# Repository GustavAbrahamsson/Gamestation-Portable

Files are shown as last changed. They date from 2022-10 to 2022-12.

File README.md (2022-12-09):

# Gamestation-Portable

A portable gaming console with a 128x64 OLED monochrome screen, two D-pads and an ESP32-S2

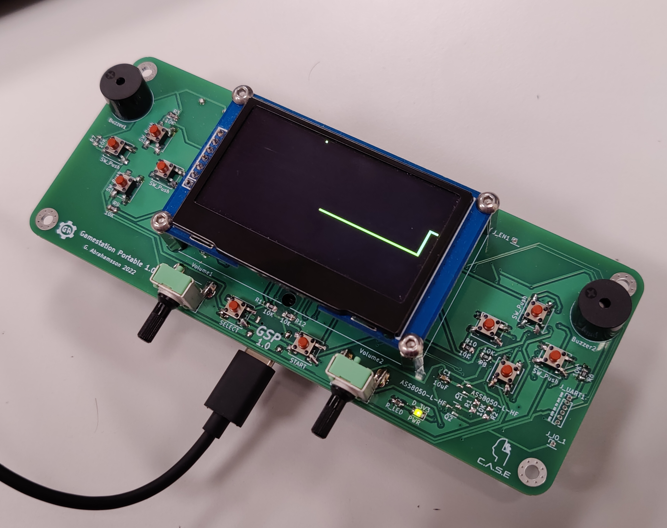
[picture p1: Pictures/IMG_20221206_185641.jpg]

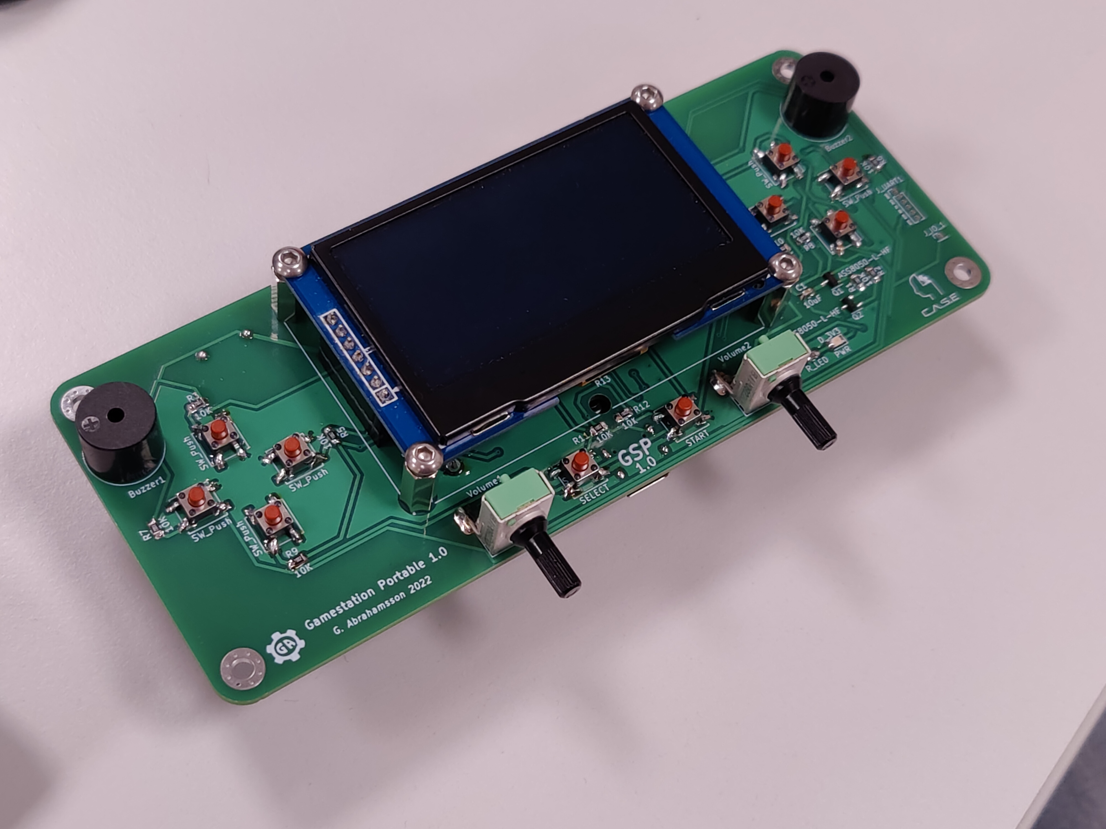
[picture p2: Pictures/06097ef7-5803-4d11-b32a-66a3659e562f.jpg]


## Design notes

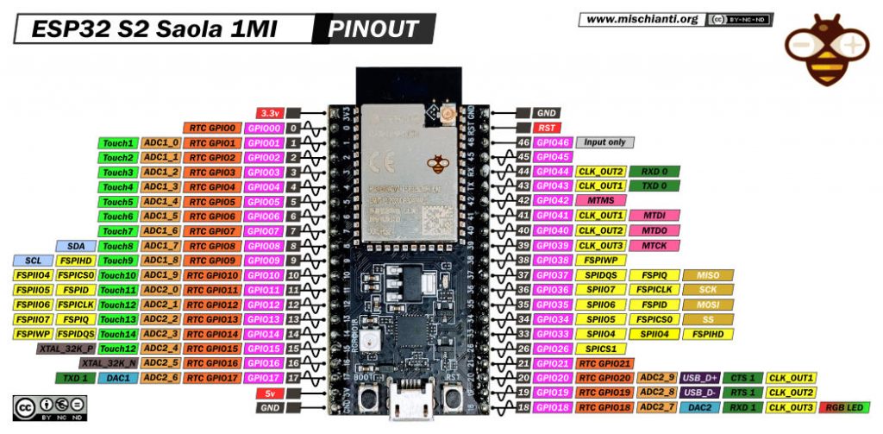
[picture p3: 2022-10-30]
Electronics/ESP32-S2-Saola-1MI-pinout-mischianti-low-1024x503.jpg

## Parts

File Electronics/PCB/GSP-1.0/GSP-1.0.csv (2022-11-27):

Id | Designator | Package | Quantity | Designation | Supplier and ref
1 | C5,C4,C1 | C_0805_2012Metric_Pad1.18x1.45mm_HandSolder | 3 | 10uF
2 | SW5,SW6,SW7,SW4,SW2,SW3,SW1,SW8 | SW_Push_1P1T_NO_CK_KSC6xxJ | 8 | SW_Push
3 | R8,R7,R5,R1,R2,R11,R6,R12,R9,R10,R3,EN_Pull-up1,R4 | R_0805_2012Metric_Pad1.20x1.40mm_HandSolder | 13 | 10K
4 | Q1,Q2 | SOT-23 | 2 | ASS8050-L-HF
5 | J_EN1,J_IO_1 | PinHeader_1x01_P1.27mm_Vertical | 2 | Conn_01x01_Male
6 | START1 | SW_Push_1P1T_NO_CK_KSC6xxJ | 1 | START
7 | R_LED1 | R_0805_2012Metric_Pad1.20x1.40mm_HandSolder | 1 | R_LED
8 | Volume2 | Potentiometer_Alps_RK09K_Single_Horizontal | 1 | R_Buzzer2
9 | BZ2 | Buzzer_12x9.5RM7.6 | 1 | Buzzer2
10 | U2 | 128x64 2.42 inch OLED display | 1 | 128x64_2.42_OLED"
11 | R13,R14 | R_0805_2012Metric_Pad1.20x1.40mm_HandSolder | 2 | 5.1K
12 | SELECT1 | SW_Push_1P1T_NO_CK_KSC6xxJ | 1 | SELECT
13 | Volume1 | Potentiometer_Alps_RK09K_Single_Horizontal | 1 | R_Buzzer1
14 | BZ1 | Buzzer_12x9.5RM7.6 | 1 | Buzzer1
15 | J_UART1 | PinHeader_1x06_P1.27mm_Vertical | 1 | Conn_01x06_Male
16 | D_3V3 | LED_0805_2012Metric_Pad1.15x1.40mm_HandSolder | 1 | PWR
17 | U4,U3 | SOT-223-3_TabPin2 | 2 | AZ1117-3.3
18 | C2 | C_0805_2012Metric_Pad1.18x1.45mm_HandSolder | 1 | 22uF
19 | C3 | C_0805_2012Metric_Pad1.18x1.45mm_HandSolder | 1 | 0.1uF
20 | SW_PWR1 | Slide-SW-GF-1123-1110 | 1 | SW_SPST
21 | J1 | USB_C_Receptacle_HRO_TYPE-C-31-M-12 | 1 | USB_C_Receptacle_USB2.0
22 | BT1 | 3xAA holder (534-2464) | 1 | Battery_pack
23 | U1 | XCVR_ESP32-S2-WROOM-I | 1 | ESP32-S2-WROOM-I

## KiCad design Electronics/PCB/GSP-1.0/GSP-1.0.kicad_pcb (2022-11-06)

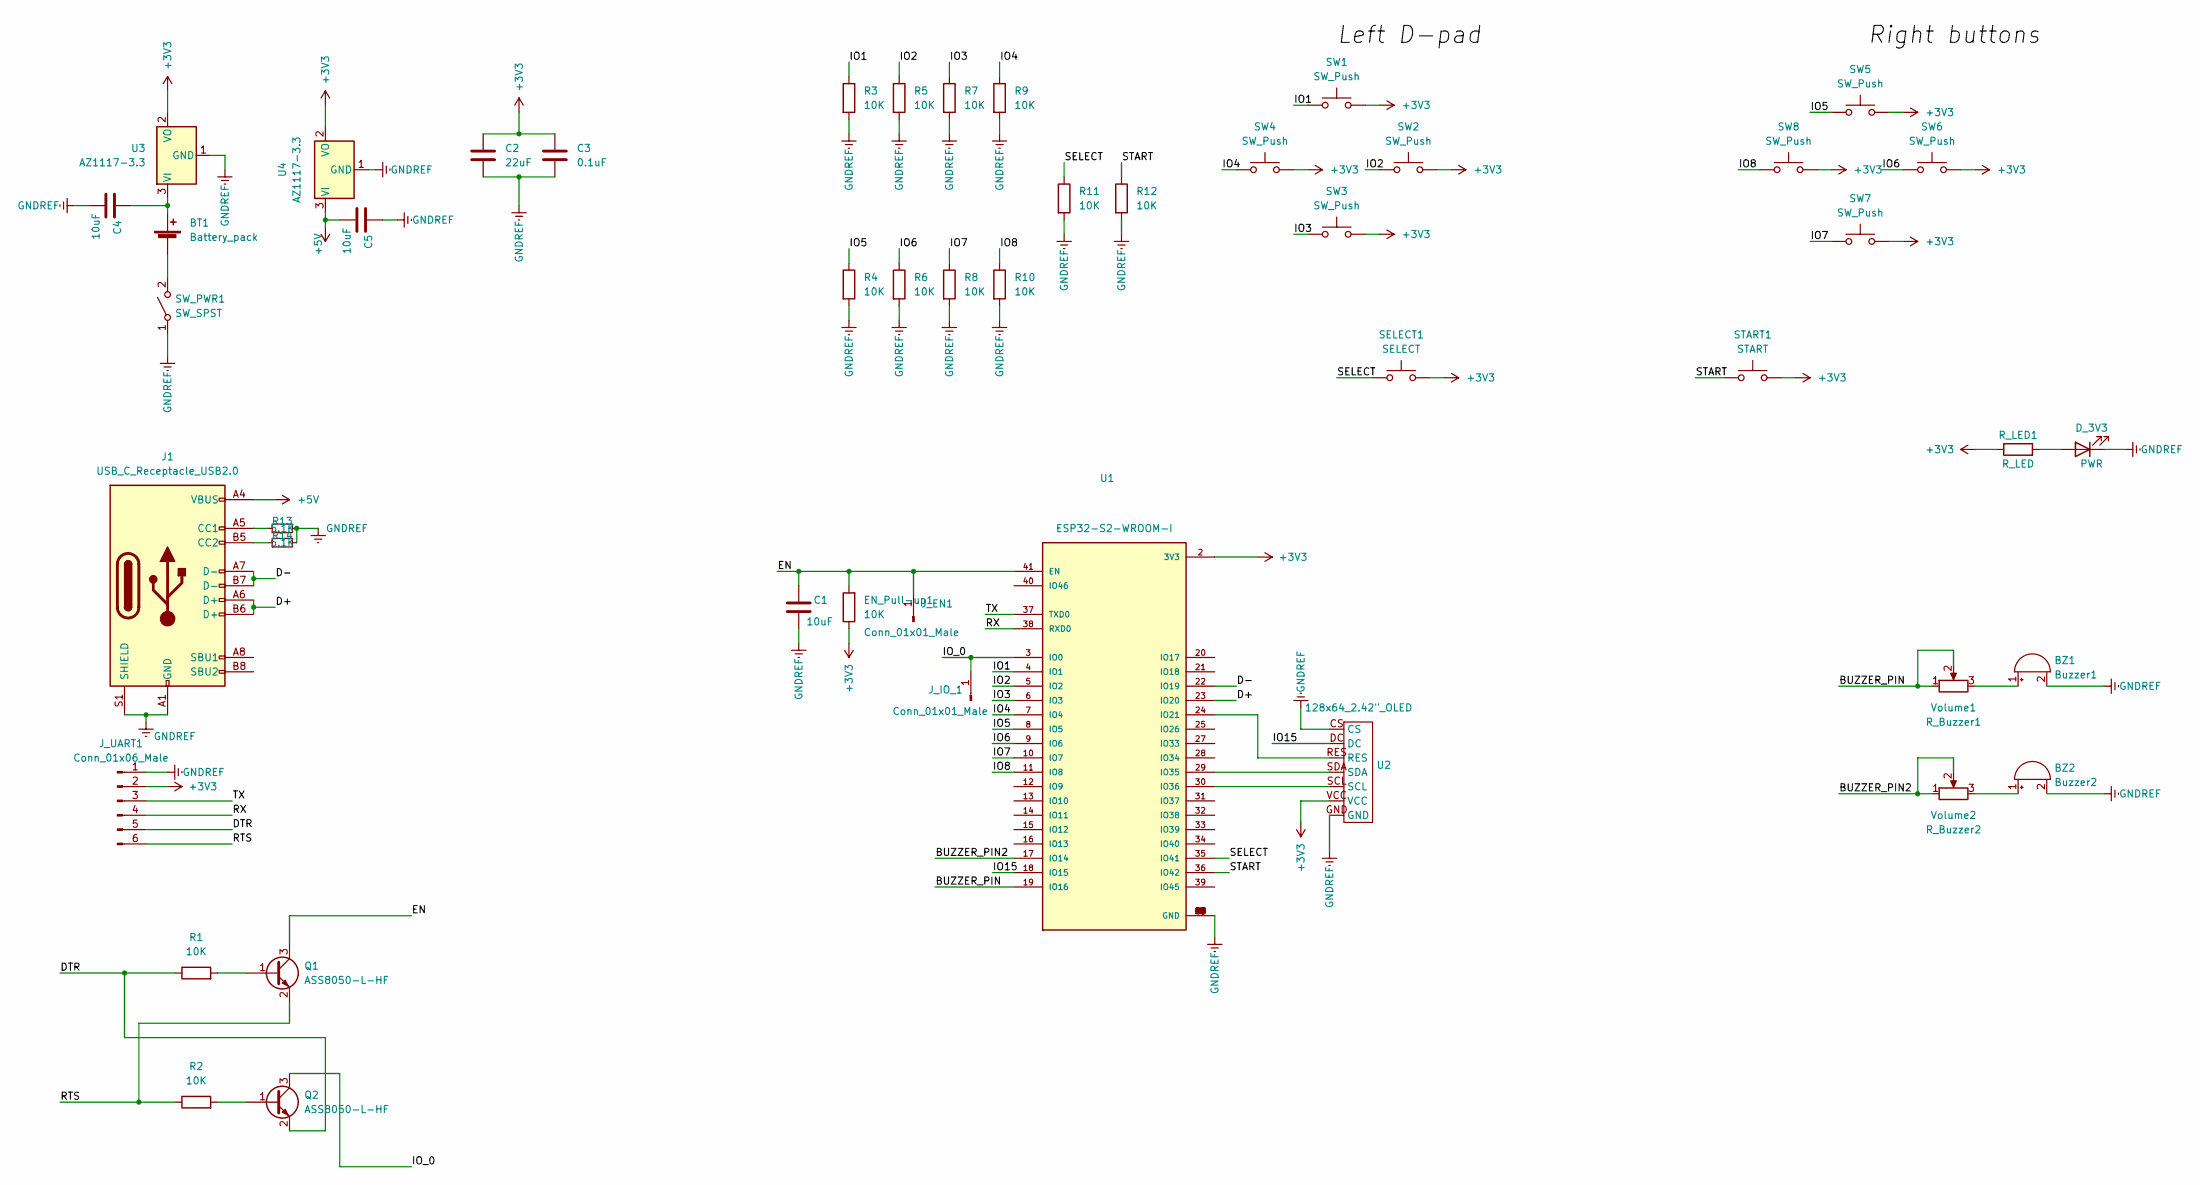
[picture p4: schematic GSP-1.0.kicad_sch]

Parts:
BT1: Battery_pack; 3xAA holder (534-2464)
BZ1: Buzzer1; Buzzer_12x9.5RM7.6
BZ2: Buzzer2; Buzzer_12x9.5RM7.6
C1, C4, C5: 10uF; C_0805_2012Metric_Pad1.18x1.45mm_HandSolder
C2: 22uF; C_0805_2012Metric_Pad1.18x1.45mm_HandSolder
C3: 0.1uF; C_0805_2012Metric_Pad1.18x1.45mm_HandSolder
D_3V3: PWR; LED_0805_2012Metric_Pad1.15x1.40mm_HandSolder
EN_Pull-up1: 10K; R_0805_2012Metric_Pad1.20x1.40mm_HandSolder
J1: USB_C_Receptacle_USB2.0; USB_C_Receptacle_HRO_TYPE-C-31-M-12
J_EN1: Conn_01x01_Male; PinHeader_1x01_P1.27mm_Vertical
J_IO_1: Conn_01x01_Male; PinHeader_1x01_P1.27mm_Vertical
J_UART1: Conn_01x06_Male; PinHeader_1x06_P1.27mm_Vertical
Q1, Q2: ASS8050-L-HF; SOT-23
R1, R2, R3, R4, R5, R6, R7, R8, R9, R10, R11, R12: 10K; R_0805_2012Metric_Pad1.20x1.40mm_HandSolder
R13, R14: 5.1K; R_0805_2012Metric_Pad1.20x1.40mm_HandSolder
R_LED1: R_LED; R_0805_2012Metric_Pad1.20x1.40mm_HandSolder
SELECT1: SELECT; SW_Push_1P1T_NO_CK_KSC6xxJ
START1: START; SW_Push_1P1T_NO_CK_KSC6xxJ
SW1, SW2, SW3, SW4, SW5, SW6, SW7, SW8: SW_Push; SW_Push_1P1T_NO_CK_KSC6xxJ
SW_PWR1: SW_SPST; Slide-SW-GF-1123-1110
U1: ESP32-S2-WROOM-I; XCVR_ESP32-S2-WROOM-I; PARTREV v1.3
U2: 128x64_2.42"_OLED; 128x64 2.42 inch OLED display
U3, U4: AZ1117-3.3; SOT-223-3_TabPin2
Volume1: R_Buzzer1; Potentiometer_Alps_RK09K_Single_Horizontal
Volume2: R_Buzzer2; Potentiometer_Alps_RK09K_Single_Horizontal

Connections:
+3V3: C2.1, C3.1, EN_Pull-up1.1, J_UART1.2, R_LED1.1, SELECT1.2, START1.2, SW1.2, SW2.2, SW3.2, SW4.2, SW5.2, SW6.2, SW7.2, SW8.2, U1.2 (3V3), U2.VCC, U3.2 (VO), U4.2 (VO)
+5V: C5.1, J1.A4 (VBUS), J1.A9 (VBUS), J1.B4 (VBUS), J1.B9 (VBUS), U4.3 (VI)
/BUZZER_PIN: U1.19 (IO16), Volume1.1, Volume1.2
/BUZZER_PIN2: U1.17 (IO14), Volume2.1, Volume2.2
/D+: J1.A6 (D+), J1.B6 (D+), U1.23 (IO20)
/D-: J1.A7 (D-), J1.B7 (D-), U1.22 (IO19)
/DTR: J_UART1.5, Q2.2 (E), R1.1
/EN: C1.2, EN_Pull-up1.2, J_EN1.1, Q1.3 (C), U1.41 (EN)
/IO1: R3.1, SW1.1, U1.4 (IO1)
/IO2: R5.1, SW2.1, U1.5 (IO2)
/IO3: R7.1, SW3.1, U1.6 (IO3)
/IO4: R9.1, SW4.1, U1.7 (IO4)
/IO5: R4.1, SW5.1, U1.8 (IO5)
/IO6: R6.1, SW6.1, U1.9 (IO6)
/IO7: R8.1, SW7.1, U1.10 (IO7)
/IO8: R10.1, SW8.1, U1.11 (IO8)
/IO15: U1.18 (IO15), U2.DC
/IO_0: J_IO_1.1, Q2.3 (C), U1.3 (IO0)
/RTS: J_UART1.6, Q1.2 (E), R2.1
/RX: J_UART1.4, U1.38 (RXD0)
/SELECT: R11.1, SELECT1.1, U1.35 (IO41)
/START: R12.1, START1.1, U1.36 (IO42)
/TX: J_UART1.3, U1.37 (TXD0)
GNDREF: BZ1.2 (+), BZ2.2 (+), C1.1, C2.2, C3.2, C4.1, C5.2, D_3V3.1 (K), J1.A1 (GND), J1.A12 (GND), J1.B1 (GND), J1.B12 (GND), J1.S1 (SHIELD), J_UART1.1, R3.2, R4.2, R5.2, R6.2, R7.2, R8.2, R9.2, R10.2, R11.2, R12.2, R13.2, R14.2, SW_PWR1.1 (A), U1.1 (GND), U1.26 (GND), U1.42 (GND), U1.43 (GND), U1.44 (GND), U1.45 (GND), U1.46 (GND), U1.47 (GND), U1.48 (GND), U1.49 (GND), U1.50 (GND), U1.51 (GND), U2.CS, U2.GND, U3.1 (GND), U4.1 (GND)
unnamed: BT1.1 (+), C4.2, U3.3 (VI)
unnamed: BT1.2 (-), SW_PWR1.2 (B)
unnamed: BZ1.1 (-), Volume1.3
unnamed: BZ2.1 (-), Volume2.3
unnamed: D_3V3.2 (A), R_LED1.2
unnamed: J1.A5 (CC1), R13.1
unnamed: J1.B5 (CC2), R14.1
unnamed: Q1.1 (B), R1.2
unnamed: Q2.1 (B), R2.2
unnamed: U1.24 (IO21), U2.RES
unnamed: U1.29 (IO35), U2.SDA
unnamed: U1.30 (IO36), U2.SCL

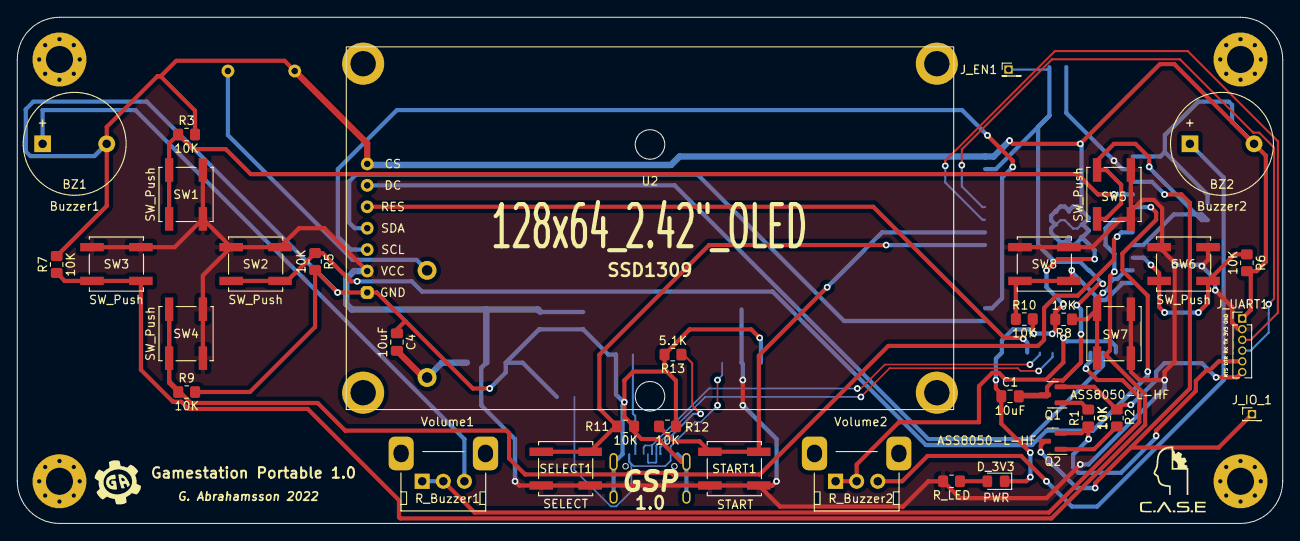
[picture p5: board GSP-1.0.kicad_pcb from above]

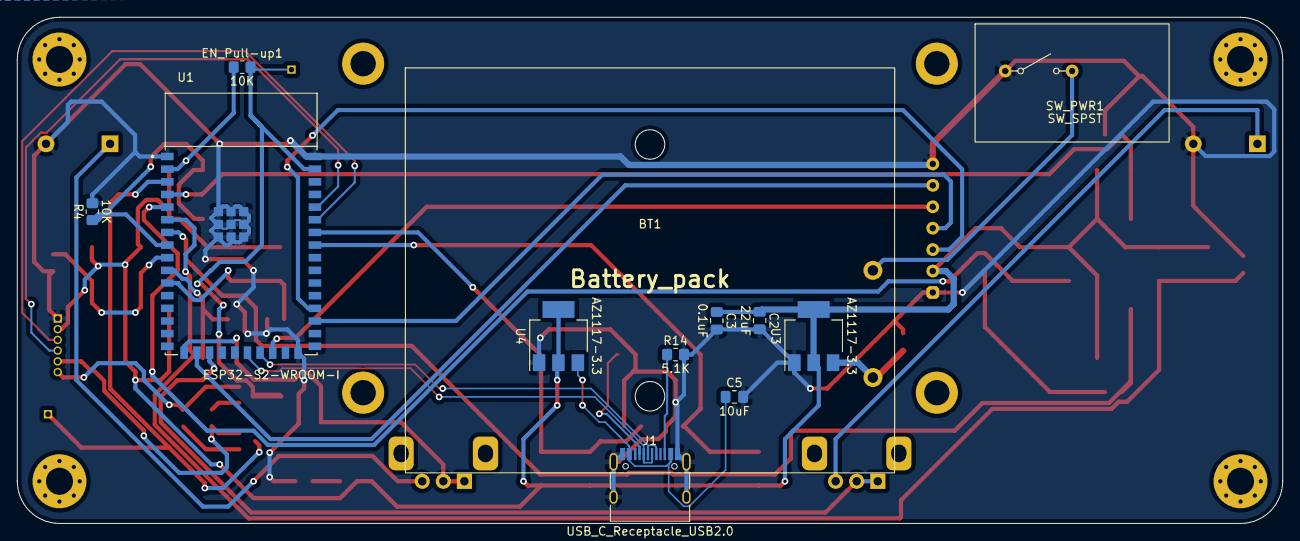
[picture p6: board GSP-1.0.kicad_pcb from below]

Board: 2 copper layers, 150.0 x 60.0 mm, 48 parts (12 on the bottom side), 36 nets.

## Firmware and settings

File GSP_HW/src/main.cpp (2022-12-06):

#include <SPI.h>
#include <Wire.h>
#include <Adafruit_GFX.h>
#include <Adafruit_SSD1306.h>
#include <Arduino.h>
#include <ctime>
#include <cstdlib>
#include <vector>
#include <iostream>

std::pair<uint8_t,uint8_t> pos;

typedef std::vector<std::vector<bool>> BitMatrix;

#include "Definitions.h"
#include "Graphics/Graphics.cpp"
#include "Display.h"
#include "Classes.h"
#include "BallBouncing.h"
#include "example_code.h"
#include "ButtonHandler.h"

#include "Game_of_Life.cpp"
#include "Snake.h"
#include "Snake.cpp"

#define GROUND_HEIGHT 7

#include <Tone32.h>

uint32_t lastTime = 0;
uint32_t lastTime2 = 0;

uint32_t currentTime = 0;
uint32_t mainTimerPeriod = 20;
uint32_t mainLastTime = 0;

//Snake* snake = NULL;

void drawEnvironment(){
   //drawLine(0, SCREEN_HEIGHT - 1 - GROUND_HEIGHT, SCREEN_WIDTH - 1, SCREEN_HEIGHT - 1 - GROUND_HEIGHT);
   fillRectangle(0, SCREEN_HEIGHT - 1 - GROUND_HEIGHT, SCREEN_WIDTH - 1, SCREEN_HEIGHT - 1 - GROUND_HEIGHT);
   display.display();
}

void randomSpawns(){
   /*
   for(int i = 0; i < 2; i++){
      for(int j = 0; j < 4; j++){
         spawnAsset(20 + 30*j, 15 + 30 * i, "beehiveExplosion");
      }
   }*/
   spawnObject(70, 20, "GliderUR");
   spawnObject(70, 40, "GliderUR", 90);
   spawnObject(60, 40, "GliderUR", 180);
   spawnObject(60, 20, "GliderUR", -90);
   /*
   for(int i = 0; i < 6; i++){
      for(int j = 0; j < 12; j++){
         spawnObject(10*j, 10*i, "GliderDL", 0);
      }
   }*/
}

uint16_t rampTone = 2000;
uint16_t rampTone2 = 5;
uint16_t rampTone3 = 10000;

uint16_t counter = 0;

void soundIteration(){
      rampTone -= 100;
      tone(BUZZER_PIN, rampTone, 5, 0);
      if (rampTone < 5){
         rampTone = 2000;
         counter++;
      }

      rampTone2 += 100;
      //tone(BUZZER_PIN, rampTone2, 5, 0);
      if (rampTone2 > 5000) rampTone2 = 5;

      rampTone3 -= 100;
      //tone(BUZZER_PIN, rampTone3, 5, 0);
      if (rampTone3 < 5000) rampTone3 = 10000;

      //Serial.println(counter);

      if (counter > 30){
         delay(2000);
         counter = 0;
      }

}

void soundLoop(void * parameter){
   // TaskCreate works really good on e.g. lolin32 since it has seveal cores, but
   // the ESP32-S2 only has one core. Having two tasks on the same core really slowed
   // things down.
   for(;;){
      soundIteration();
   }
}

void setupInputs(){
   pinMode(BTN0, INPUT_PULLDOWN);
   pinMode(BTN1, INPUT_PULLDOWN);
   pinMode(BTN2, INPUT_PULLDOWN);
   pinMode(BTN3, INPUT_PULLDOWN);

   pinMode(BTN4, INPUT_PULLDOWN);
   pinMode(BTN5, INPUT_PULLDOWN);
   pinMode(BTN6, INPUT_PULLDOWN);
   pinMode(BTN7, INPUT_PULLDOWN);
   
   pinMode(SELECT, INPUT_PULLDOWN);
   pinMode(START, INPUT_PULLDOWN);
}

void setupOutputs(){
   ledcAttachPin(BUZZER_PIN, BZR_CHANNEL);
   ledcAttachPin(BUZZER_PIN_2, BZR_2_CHANNEL);
}

void setup() {
    Serial.begin(115200);
    Serial.println("Serial begun");
    setupInputs();
    setupOutputs();

    // Beep beep
    tone1(1750);
    delay(100);
    tone1(0);
    delay(25);
    tone1(1750);
    delay(100);
    tone1(0);

    delay(2000);

    srand(time(0));

    if(!display.begin(SSD1306_SWITCHCAPVCC)) {
        Serial.println(F("SSD1306 allocation failed"));
        while(1);
    }

    display.clearDisplay();
    //initGraphics();
    //initGameOfLife(0);
    //randomSpawns();
    delay(3000);

    setupSnake();

    display.display();

}


void loop(){
   
    currentTime = millis();

    if (currentTime - mainLastTime > mainTimerPeriod){ // Main execution frequency
        mainLastTime = currentTime;

        readButtons();

        filterButtons();

        playBzrWithButtons();

    }

    snakeGame(currentTime);

}



   //gameOfLife();
   /*
   drawLine(renderRange[0], renderRange[2], renderRange[1], renderRange[2]);
   drawLine(renderRange[1], renderRange[2], renderRange[1], renderRange[3]);
   drawLine(renderRange[1], renderRange[3], renderRange[0], renderRange[3]);
   drawLine(renderRange[0], renderRange[3], renderRange[0], renderRange[2]);
   */
   
   /*
   if(currentTime - lastTime > 1000){
      lastTime = currentTime;

   }if(currentTime - lastTime2 > 10000){
      lastTime2 = currentTime;
      clear_display();
      //initGameOfLife(0);
      //randomSpawns();
   }*/

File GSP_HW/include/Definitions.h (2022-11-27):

//ESP32-S2-WROOM-I

// D-pad pins
#define BTN0 1
#define BTN1 2
#define BTN2 3
#define BTN3 4

#define BTN4 5
#define BTN5 6
#define BTN6 7
#define BTN7 8

#define SELECT 41
#define START 42

// Pins used for the SPI screen
#define OLED_SDA   35 // FSPID
#define OLED_SCK   36 // FSPICLK
#define OLED_DC    15
#define OLED_CS    34 // GND
#define OLED_RESET 21


#define BUZZER_PIN 16
#define BZR_CHANNEL 0

#define BUZZER_PIN_2 14
#define BZR_2_CHANNEL 5

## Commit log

2022-10-27 Begin PCB
    [GSP-1.0.kicad_pcb, GSP-1.0.kicad_sch]
2022-10-30 Fix ESP32 version
    [GSP-1.0.kicad_pcb, GSP-1.0.kicad_sch]
2022-10-31 PCB almost finished, but lots of errors
    [GSP-1.0.kicad_pcb, GSP-1.0.kicad_sch]
2022-11-02 Fix PCB
    [GSP-1.0.kicad_pcb, GSP-1.0.kicad_sch]
2022-11-04 Update PCB
    [GSP-1.0.kicad_pcb, GSP-1.0.kicad_sch]
2022-11-06 Final 1.0 version with PCB ordered
    [GSP-1.0-B_Cu.gbr, GSP-1.0-B_Mask.gbr, GSP-1.0-B_Paste.gbr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]
2022-11-23 Add code after first assembly of PCB
2022-11-27 Button testing
    [GSP-1.0.csv]
2022-11-28 Finish buttonHandler and buttonFilter, begin Snake
2022-12-04 Snake progress
    Borders are problematic, the deque manages to move further away
    [ButtonHandler.h, Display.h, main.cpp]
2022-12-04 Working snake with some features missing
    [Display.h]
2022-12-06 Implement self-bite, game over and bugs
    [Display.h, main.cpp]
